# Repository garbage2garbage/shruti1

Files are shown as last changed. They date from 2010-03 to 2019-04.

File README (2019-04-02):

Shruti-1, a digital/analog hybrid MIDI monosynth.

Copyright 2009 Emilie Gillet (emilie.o.gillet@gmail.com)

# The firmware is released under a GPL3.0 license. It includes external code from the following sources:
- Parts of the Arduino library (real time clock and timed delay for software serial).
- Parts of M J Oldfield's makefile for Arduino project.
- A reimplementation of the formant synthesis algorithm used in Peter Knight's Cantarino speech synthesizer.

# The PCB layouts and schematics (in /hardware/shruti/hardware_design) are released under a Creative Commons cc-by-nc-sa 3.0 license.

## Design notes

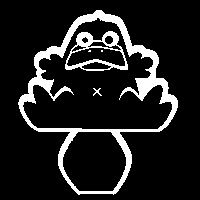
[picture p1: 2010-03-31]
hardware/shruti/hardware_design/pcb/platypus.bmp

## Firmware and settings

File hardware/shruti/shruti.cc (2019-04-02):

// Copyright 2009 Emilie Gillet.
//
// Author: Emilie Gillet (emilie.o.gillet@gmail.com)
//
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
#include "hardware/hal/adc.h"
#include "hardware/hal/audio_output.h"
#include "hardware/hal/devices/output_array.h"
#include "hardware/hal/devices/shift_register.h"
#include "hardware/hal/gpio.h"
#include "hardware/hal/init_atmega.h"
#include "hardware/hal/input_array.h"
#include "hardware/hal/serial.h"
#include "hardware/hal/time.h"
#include "hardware/hal/timer.h"
#include "hardware/midi/midi.h"
#include "hardware/shruti/display.h"
#include "hardware/shruti/editor.h"
#include "hardware/shruti/synthesis_engine.h"
#include "hardware/utils/task.h"

using namespace hardware_hal;
using namespace hardware_midi;
using namespace hardware_shruti;

using hardware_utils::NaiveScheduler;
using hardware_utils::Task;

// Midi input.
Serial<SerialPort0, 31250, BUFFERED, POLLED> midi_io;

// Input event handlers.
typedef InputArray<
    AnalogInput<kPinAnalogInput>,
    kNumEditingPots,
    8> Pots;

typedef InputArray<
    DigitalInput<kPinDigitalInput>,
    kNumGroupSwitches + 2> Switches;

PwmOutput<kPinVcfCutoffOut> vcf_cutoff_out;
PwmOutput<kPinVcfResonanceOut> vcf_resonance_out;
PwmOutput<kPinVcaOut> vca_out;

Pots pots;
Switches switches;

// Shift register for input multiplexer.
ShiftRegister<
    Gpio<kPinInputLatch>,
    Gpio<kPinClk>,
    Gpio<kPinData>, 8, MSB_FIRST> input_mux;

// LED array.
OutputArray<
    Gpio<kPinOutputLatch>, 
    Gpio<kPinClk>,
    Gpio<kPinData>, kNumPages, 4, MSB_FIRST, false> leds;

// Audio output on pin 3.
AudioOutput<PwmOutput<kPinVcoOut>, kAudioBufferSize, kAudioBlockSize> audio_out;

MidiStreamParser<SynthesisEngine> midi_parser;

static const uint16_t kDetailsPageDelay = 900;

// What follows is a list of "tasks" - short functions handling a particular
// aspect of the synth (rendering audio, updating the LCD display, etc). they
// are called in sequence, with some tasks being more frequently called than
// others, by the Scheduler.
void UpdateLedsTask() {
  leds.Clear();
  if (editor.current_page() == PAGE_MOD_MATRIX) {
    uint8_t current_modulation_source_value = engine.modulation_source(0,
        engine.patch().modulation_matrix.modulation[
            editor.subpage()].source);
    leds.set_value(PAGE_MOD_MATRIX, current_modulation_source_value >> 4);
  } else if (editor.current_page() == PAGE_PERFORMANCE) {
    for (uint8_t i = 0; i < kNumModulationDestinations; ++i) {
      leds.set_value(i, engine.voice(0).modulation_destination(i) >> 4);
    }
  } else {
    leds.set_value(editor.current_page(), 15);
  }
  // The led of the arpeggiator page flashes strongly on the 0-th step and
  // weakly on the other steps which are a multiple of 4.
  if (engine.voice_controller().active()) {
    if (!(engine.voice_controller().step() & 3)) {
      leds.set_value(PAGE_LOAD_SAVE, engine.voice_controller().step() ? 1 : 15);
    }
  }
  leds.Output();
}

void UpdateDisplayTask() {
  display.Update();
}

void InputTask() {
  Switches::Event switch_event;
  Pots::Event pot_event;
  static uint8_t idle;
  static uint8_t target_page_type;
TASK_BEGIN_NEAR
  while (1) {
    idle = 0;
    target_page_type = PAGE_TYPE_ANY;
    
    // Read the switches.
    switch_event = switches.Read();
    
    // If a button was pressed, perform the action. Otherwise, if nothing
    // happened for 1.5s, update the idle flag.
    if (switch_event.event == EVENT_NONE) {
      if (switch_event.time > kDetailsPageDelay) {
        idle = 1;
      }
    } else {
      if (switch_event.event == EVENT_RAISED && switch_event.time > 100) {
        uint8_t id = switch_event.id;
        uint8_t hold_time = static_cast<uint16_t>(switch_event.time) >> 8;
        if (id < kNumGroupSwitches) {
          if (hold_time >= 3) {  // 0.768 seconds
            editor.DoShiftFunction(id, hold_time);
          } else {
            editor.ToggleGroup(id);
          }
          target_page_type = PAGE_TYPE_SUMMARY;
        } else {
          editor.HandleIncrement(id == kNumGroupSwitches ? -1 : 1);
          target_page_type = PAGE_TYPE_DETAILS;
        }
      }
    }
    
    // Select which analog/digital inputs we want to read by a write to the
    // multiplexer register.
    input_mux.Write((pots.active_input() << 3) | switches.active_input());    
    pot_event = pots.Read();
    
    // Update the editor if something happened.
    // Revert back to the main page when nothing happened for 1.5s.
    if (pot_event.event == EVENT_NONE) {
      if (idle && pot_event.time > kDetailsPageDelay) {
        target_page_type = PAGE_TYPE_SUMMARY;
      }
    } else {
      editor.HandleInput(pot_event.id, pot_event.value);
      target_page_type = PAGE_TYPE_DETAILS;
    }
    TASK_SWITCH;
    
    if (target_page_type == PAGE_TYPE_SUMMARY) {
      editor.DisplaySummary();
    } else if (target_page_type == PAGE_TYPE_DETAILS) {
      editor.DisplayDetails();
    }
    TASK_SWITCH;
  }
TASK_END
}

uint8_t current_cv;

void CvTask() {
  ++current_cv;
  if (current_cv >= kNumCvInputs) {
    current_cv = 0;
  }
  engine.set_cv(current_cv, Adc::Read(kPinCvInput + current_cv) >> 2);
}

void MidiTask() {
  // Always flush the MIDI buffer before continuing. This makes unlikely the
  // situation where MIDI bytes are dropped... at the cost of a more glitchy
  // audio output in case of MIDI overloading.
  uint8_t status = 0;
  while (midi_io.readable()) {
    uint8_t value = midi_io.ImmediateRead();
    
    // Copy the byte to the MIDI output (thru). We could use Overwrite here
    // since the output rate is the same as the input rate, which ensures that
    // 0.32ms have elapsed between the writes.
    midi_io.Write(value);
    
    // Also, parse the message.
    status = midi_parser.PushByte(value);
    if (engine.patch().kbd_midi_channel >= 17) {
      break;
    }
  }
  // Display a status indicator on the LCD to indicate that a message has
  // been received. This could be done as well in the synthesis engine code
  // or in the MIDI parser, but I'd rather keep the UI code separate.
  switch (status & 0xf0) {
    // Note on/off.
    case 0x90:
      display.set_status('\x01');
      break;
    // Controller.
    case 0xb0:
      display.set_status('\x05');
      break;
    // Bender.
    case 0xe0:
      display.set_status('\x02');
      break;
    // Special messages.
    case 0xf0:
      // Display a status indicator to monitor SysEx patch reception.
      if (status == 0xf0 || status == 0xf7) {
        switch (engine.patch().sysex_reception_state()) {
          case RECEIVING_DATA:
            display.set_status('~');
            break;
          case RECEPTION_OK:
            display.set_status('+');
            engine.TouchPatch();
            break;
          case RECEPTION_ERROR:
            display.set_status('#');
            break;
        }
      }
      break;
  }
}

void AudioRenderingTask() {
  if (audio_out.writable_block()) {
    engine.Control();
    if (engine.voice(0).dead()) {
      for (uint8_t i = kAudioBlockSize; i > 0 ; --i) {
        audio_out.Overwrite(128);
      }
    } else {
      for (uint8_t i = kAudioBlockSize; i > 0 ; --i) {
        engine.Audio();
        audio_out.Overwrite(engine.voice(0).signal());
      }
    }
    vcf_cutoff_out.Write(engine.voice(0).cutoff());
    vcf_resonance_out.Write(engine.voice(0).resonance());
    vca_out.Write(engine.voice(0).vca());
  }
}

uint16_t previous_num_glitches;

// This task displays a '!' in the status area of the LCD displays whenever
// a discontinuity occurred in the audio rendering. Even if the code is
// optimized in such a way that it never occurs, I'd rather keep it here in
// case new features are implemented and need performance monitoring.
// This code uses 42 bytes.
void AudioGlitchMonitoringTask() {
  uint16_t num_glitches = audio_out.num_glitches();
  if (num_glitches != previous_num_glitches) {
    previous_num_glitches = num_glitches;
    display.set_status('!');
  }
}

typedef NaiveScheduler<kSchedulerNumSlots> Scheduler;

Scheduler scheduler;

/* static */
template<>
Task Scheduler::tasks_[] = {
    { &AudioRenderingTask, 16 },
    { &MidiTask, 6 },
    { &UpdateLedsTask, 4 },
    { &UpdateDisplayTask, 2 },
#ifdef HAS_GLITCH_MONITORING
    { &AudioGlitchMonitoringTask, 1 },
#endif  // HAS_GLITCH_MONITORING
    { &InputTask, 2 },
    { &CvTask, 1 },
};

TIMER_2_TICK {
  display.Tick();
  audio_out.EmitSample();
}

void Init() {
  scheduler.Init();
  display.Init();
  editor.Init();
  audio_out.Init();

  // Initialize all the PWM outputs, in 31.25kHz, phase correct mode.
  Timer<1>::set_prescaler(1);
  Timer<1>::set_mode(TIMER_PWM_PHASE_CORRECT);
  Timer<2>::set_prescaler(1);
  Timer<2>::set_mode(TIMER_PWM_PHASE_CORRECT);
  Timer<2>::Start();
  vcf_cutoff_out.Init();
  vcf_resonance_out.Init();
  vca_out.Init();
  
  display.SetBrightness(29);
  display.SetCustomCharMap(character_table[0], 8);
  editor.DisplaySplashScreen(STR_RES_MUTABLE____V0_59);
  
  midi_io.Init();
  pots.Init();
  switches.Init();
  DigitalInput<kPinDigitalInput>::EnablePullUpResistor();
  input_mux.Init();
  leds.Init();  
  
  engine.Init();
}

int main(void) {
  InitAtmega(false);  // Do not initialize timers 1 & 2.
  Init();
  scheduler.Run();
}

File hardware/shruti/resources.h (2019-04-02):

// Copyright 2009 Emilie Gillet.
//
// Author: Emilie Gillet (emilie.o.gillet@gmail.com)
//
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
// -----------------------------------------------------------------------------
//
// Resources definitions.
//
// Automatically generated with:
// make resources


#ifndef HARDWARE_SHRUTI_RESOURCES_H_
#define HARDWARE_SHRUTI_RESOURCES_H_


#include "hardware/base/base.h"

#include <avr/pgmspace.h>


#include "hardware/resources/resources_manager.h"
namespace hardware_shruti {

typedef uint8_t ResourceId;

extern const prog_char* string_table[];

extern const prog_uint16_t* lookup_table_table[];

extern const prog_uint8_t* waveform_table[];

extern const prog_uint8_t* character_table[];

extern const prog_uint16_t lut_res_lfo_increments[] PROGMEM;
extern const prog_uint16_t lut_res_env_portamento_increments[] PROGMEM;
extern const prog_uint16_t lut_res_oscillator_increments[] PROGMEM;
extern const prog_uint16_t lut_res_fm_frequency_ratios[] PROGMEM;
extern const prog_uint16_t lut_res_scale_just[] PROGMEM;
extern const prog_uint16_t lut_res_scale_pythagorean[] PROGMEM;
extern const prog_uint16_t lut_res_scale_1_4_eb[] PROGMEM;
extern const prog_uint16_t lut_res_scale_1_4_e[] PROGMEM;
extern const prog_uint16_t lut_res_scale_1_4_ea[] PROGMEM;
extern const prog_uint16_t lut_res_scale_bhairav[] PROGMEM;
extern const prog_uint16_t lut_res_scale_gunakri[] PROGMEM;
extern const prog_uint16_t lut_res_scale_marwa[] PROGMEM;
extern const prog_uint16_t lut_res_scale_shree[] PROGMEM;
extern const prog_uint16_t lut_res_scale_purvi[] PROGMEM;
extern const prog_uint16_t lut_res_scale_bilawal[] PROGMEM;
extern const prog_uint16_t lut_res_scale_yaman[] PROGMEM;
extern const prog_uint16_t lut_res_scale_kafi[] PROGMEM;
extern const prog_uint16_t lut_res_scale_bhimpalasree[] PROGMEM;
extern const prog_uint16_t lut_res_scale_darbari[] PROGMEM;
extern const prog_uint16_t lut_res_scale_rageshree[] PROGMEM;
extern const prog_uint16_t lut_res_scale_khamaj[] PROGMEM;
extern const prog_uint16_t lut_res_scale_mimal[] PROGMEM;
extern const prog_uint16_t lut_res_scale_parameshwari[] PROGMEM;
extern const prog_uint16_t lut_res_scale_rangeshwari[] PROGMEM;
extern const prog_uint16_t lut_res_scale_gangeshwari[] PROGMEM;
extern const prog_uint16_t lut_res_scale_kameshwari[] PROGMEM;
extern const prog_uint16_t lut_res_scale_palas_kafi[] PROGMEM;
extern const prog_uint16_t lut_res_scale_natbhairav[] PROGMEM;
extern const prog_uint16_t lut_res_scale_m_kauns[] PROGMEM;
extern const prog_uint16_t lut_res_scale_bairagi[] PROGMEM;
extern const prog_uint16_t lut_res_scale_b_todi[] PROGMEM;
extern const prog_uint16_t lut_res_scale_chandradeep[] PROGMEM;
extern const prog_uint16_t lut_res_scale_kaushik_todi[] PROGMEM;
extern const prog_uint16_t lut_res_scale_jogeshwari[] PROGMEM;
extern const prog_uint16_t lut_res_arpeggiator_patterns[] PROGMEM;
extern const prog_uint16_t lut_res_turbo_tempi[] PROGMEM;
extern const prog_uint16_t lut_res_groove_swing[] PROGMEM;
extern const prog_uint16_t lut_res_groove_shuffle[] PROGMEM;
extern const prog_uint16_t lut_res_groove_push[] PROGMEM;
extern const prog_uint16_t lut_res_groove_lag[] PROGMEM;
extern const prog_uint16_t lut_res_groove_human[] PROGMEM;
extern const prog_uint8_t wav_res_formant_sine[] PROGMEM;
extern const prog_uint8_t wav_res_formant_square[] PROGMEM;
extern const prog_uint8_t wav_res_bandlimited_square_0[] PROGMEM;
extern const prog_uint8_t wav_res_bandlimited_square_1[] PROGMEM;
extern const prog_uint8_t wav_res_bandlimited_square_2[] PROGMEM;
extern const prog_uint8_t wav_res_bandlimited_square_3[] PROGMEM;
extern const prog_uint8_t wav_res_bandlimited_square_4[] PROGMEM;
extern const prog_uint8_t wav_res_bandlimited_square_5[] PROGMEM;
extern const prog_uint8_t wav_res_bandlimited_square_6[] PROGMEM;
extern const prog_uint8_t wav_res_bandlimited_saw_0[] PROGMEM;
extern const prog_uint8_t wav_res_bandlimited_saw_1[] PROGMEM;
extern const prog_uint8_t wav_res_bandlimited_saw_2[] PROGMEM;
extern const prog_uint8_t wav_res_bandlimited_saw_3[] PROGMEM;
extern const prog_uint8_t wav_res_bandlimited_saw_4[] PROGMEM;
extern const prog_uint8_t wav_res_bandlimited_saw_5[] PROGMEM;
extern const prog_uint8_t wav_res_bandlimited_triangle_0[] PROGMEM;
extern const prog_uint8_t wav_res_bandlimited_triangle_1[] PROGMEM;
extern const prog_uint8_t wav_res_bandlimited_triangle_2[] PROGMEM;
extern const prog_uint8_t wav_res_bandlimited_triangle_3[] PROGMEM;
extern const prog_uint8_t wav_res_bandlimited_triangle_4[] PROGMEM;
extern const prog_uint8_t wav_res_bandlimited_triangle_5[] PROGMEM;
extern const prog_uint8_t wav_res_wavetable[] PROGMEM;
extern const prog_uint8_t wav_res_vowel_data[] PROGMEM;
extern const prog_uint8_t chr_res_special_characters[] PROGMEM;
#define STR_RES_PRM 0  // prm
#define STR_RES_RNG 1  // rng
#define STR_RES_OP 2  // op
#define STR_RES_TUN 3  // tun
#define STR_RES_PRT 4  // prt
#define STR_RES_PORTA 5  // porta
#define STR_RES_PARAMETER 6  // parameter
#define STR_RES_RANGE 7  // range
#define STR_RES_OPERATOR 8  // operator
#define STR_RES_DETUNE 9  // detune
#define STR_RES_OSC_BAL 10  // osc bal
#define STR_RES_SUB_OSC_ 11  // sub osc.
#define STR_RES_PATTERN 12  // pattern
#define STR_RES_GROOVE 13  // groove
#define STR_RES_OSCILLATOR_1 14  // oscillator 1
#define STR_RES_OSCILLATOR_2 15  // oscillator 2
#define STR_RES_ARPEGGIO 16  // arpeggio
#define STR_RES_PERFORMANCE 17  // performance
#define STR_RES_NONE 18  // none
#define STR_RES_BLIT 19  // blit
#define STR_RES_SAW 20  // saw
#define STR_RES_SQUARE 21  // square
#define STR_RES_TRIANG 22  // triang
#define STR_RES_CZ 23  // cz
#define STR_RES_FM 24  // fm
#define STR_RES_8BITS 25  // 8bits
#define STR_RES_PWM 26  // pwm
#define STR_RES_NOISE 27  // noise
#define STR_RES_VOWEL 28  // vowel
#define STR_RES_WAVTBL 29  // wavtbl
#define STR_RES_SWEEP 30  // sweep
#define STR_RES_ZSYNC 31  // zsync
#define STR_RES_PAD 32  // pad
#define STR_RES_1S2 33  // 1+2
#define STR_RES_1_2 34  // 1>2
#define STR_RES_1P2 35  // 1*2
#define STR_RES_1X2 36  // 1^2
#define STR_RES_CUT 37  // cut
#define STR_RES_VCA 38  // vca
#define STR_RES_PW1 39  // pw1
#define STR_RES_PW2 40  // pw2
#define STR_RES_51 41  // 1
#define STR_RES_52 42  // 2
#define STR_RES_5 43  // 
#define STR_RES_MIX 44  // mix
#define STR_RES_NOI 45  // noi
#define STR_RES_SUB 46  // sub
#define STR_RES_RES 47  // res
#define STR_RES_CUTOFF 48  // cutoff
#define STR_RES__VCA 49  //  vca
#define STR_RES_PWM1 50  // pwm1
#define STR_RES_PWM2 51  // pwm2
#define STR_RES_OSC1 52  // osc1
#define STR_RES_OSC2 53  // osc2
#define STR_RES_OSC1S2 54  // osc1+2
#define STR_RES__MIX 55  //  mix
#define STR_RES__NOISE 56  //  noise
#define STR_RES_SUBOSC 57  // subosc
#define STR_RES_RESO 58  // reso
#define STR_RES_ATK 59  // atk
#define STR_RES_WV1 60  // wv1
#define STR_RES_RT1 61  // rt1
#define STR_RES_WV2 62  // wv2
#define STR_RES_RT2 63  // rt2
#define STR_RES_SRC 64  // src
#define STR_RES_DST 65  // dst
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

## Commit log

2009-08-22 - Refactoring of LFOs as classes. - Refactoring of Display driver as static'ified class. - More informative header in the modulation matrix page.
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2009-08-22 Bug fixes and small improvements in speed and code size: - Added a 33th waveform (a copy of the 1st) as a sentinel. - Reduced the size of the blit/square code. - Renamed wavetable functions (256/64 i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
    [editor.h, oscillator.h, resources.cc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]
2009-08-23 - added crossfading between each zone's waveform, for the basic saw and square waveforms. - switched to 16kHz output. - changed the wirings to prepare for dual DAC output. - added functions for nibbl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
    [oscillator.h, resources.cc, shruti.cc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]
2009-08-23 - Moved "drivers" for external circuits in "devices" subdirectory. - Changed my name to my google id to my github id. - SPI interface + driver for 492x DACs (not used yet in the synth code for perfor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
2009-08-24 - Fixed lame bug in midi stream parser. - Fixed lame bugs in resources compiler. - MIDI! - Many bugs fixed in envelope code. - (Temporary) software VCA. - Pitch bend in -2/2 semitones range.
2009-08-25 First pass for hybrid (31.25kHz for saw/square, 15.625kHz for the rest) oscillators. !! Still glitchy for 3 square waves. !! Voice oscillator seems to be broken.
    [oscillator.h, resources.cc, resources.h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]
2009-08-26 A couple of steps towards good performances at 32kHz... - Minor cosmetic/stylistic changes. - Added status indicator in display (MIDI notes, glitches). - Sub-oscillator is now specialized, and runs a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
    [adc.cc, adc.h, init_arduino.cc]
2009-08-27 - Removed unnecessary oscillator reset code. - Removed large block of inlined asm (InterpolateTwoTables). It was not much faster and caused weird register conflicts. - Simplified the oscillators code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
    [oscillator.h, resources.cc, resources.h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]
2009-08-27 - Control signals for the curtis filter are now written to the PWM outputs. - Fixed a bug with the splashscreen+status.
    [oscillator.h, resources.cc, resources.h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]
2009-08-27 Code optimizations: - No check on disabled oscillators. This makes the code run much slower in the typical case, but makes it run faster on the worst case (and we're interested in avoiding bugs in th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
    [oscillator.h, synthesis_engine.cc]
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2009-09-03 Added EAGLE schematics and board designs.
    [Shruti-FrontPanel-v01.brd, Shruti-FrontPanel-v01.sch, Shruti-Main-v01.brd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]
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2009-09-15 - fixed minor style issues in a couple of classes. - simplified some pure stateless tasks. - implemented a very naive scheduler to adjust priorities / scan rates / refresh rates for each task. No mor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
    [Shruti-Main-v01.brd, Shruti-Main-v01.sch]
2009-09-15 - fixed the way signed parameters are defined. - remove ramp up / ramp down distinction (ramp down can be obtained with a ramp up and a negative modulation amount). - extended the size of the modulat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
    [editor.h, oscillator.h, patch.h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]
2009-09-16 - in order to save space, removed short parameter names when they were the first letters of the long name. - moved patch load/save code to the Patch class. - added easter egg. - revised oscillator pr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
    [editor.h, oscillator.h, patch.h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]
2009-09-16 - Added delay function. - Added delays before/after sending the baud rate change command to the LCD. This almost solves the "boot up in 9600bps mode" problem. - Added noinline attributes here and the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
    [init_arduino.cc]
2009-09-16 - FM and phase distortion now run at sr! - FM has been replaced by phase distortion - the results are sonically very similar anyway.
    [oscillator.h, patch.h, shruti.cc]
2009-09-17 - Renamed the Signal class Op, since all the optimized routines here are no longer specific to signal/samples manipulation. - Removed unused custom characters. Instead, added a lame "shruti-1" devana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
    [oscillator.h, resources.cc, resources.h]
2009-09-17 - Shifted the phase of all the waveforms by 90° to fix a bug with cz sweep. - Adopted a new strategy for dealing with the computational cost of the "voice" oscillator: when this algorithm is used, th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
    [oscillator.h, resources.cc, synthesis_engine.cc]
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2009-09-21 - Added a "silent" "oscillator", called "none", which is useful when processing external signals. - The envelope/LFO modulation settings directly accessible on the filter page are no longer polarized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
    [Shruti-Main-v01.brd, Shruti-Main-v01.sch]
2009-09-27 First pass on the code for style/minor issues.
    [oscillator.h, patch.h, resources.cc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]
2009-09-27 Another pass of style corrections
    [shruti.cc]
2009-09-28 Another pass of optimizations. The torture-test patch now runs without glitches!
    [oscillator.h, shruti.cc, synthesis_engine.cc]
2009-10-12 Revised schematics and PCB designs.
    [Shruti-FrontPanel-v01.brd, Shruti-FrontPanel-v01.sch, Shruti-Main-v01.brd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]
2009-10-24 main PCB update
    [Shruti-Main-v01.brd, Shruti-Main-v01.sch]
2009-11-07 PCB review
    [Shruti-FrontPanel-v01.brd, Shruti-FrontPanel-v01.sch, Shruti-Main-v01.brd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]
2009-11-08 - PCB: removed caps on 74hc595s' latches. This was stupid, indeed. - PCB: reworked the layout of the main board so that it can act as a "shield" for the arduino (less cables!!!). - PCB: added funky s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
    [Shruti-FrontPanel-v01.brd, Shruti-FrontPanel-v01.sch, Shruti-Main-v01.brd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]
2009-11-09 Added GPL notice to all source files, cc-by-nc-sa to all PCB design files
    [Shruti-FrontPanel-v01.brd, Shruti-Main-v01.brd]
2009-11-14 Minor corrections to comments/README
    [synthesis_engine.cc]
2009-11-17 Added new PCB layouts: front panel shrinked to 50% of its original size, main board with ATMega328P
    [Shruti-FrontPanel-v01.brd, Shruti-FrontPanel-v02.brd, Shruti-FrontPanel-v02.sch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]
2009-11-20 New power supply
    [Shruti-FrontPanel-v02.brd, Shruti-Main-v02.brd, Shruti-Main-v02.sch]
2009-11-20 Minor PCB tweaks
    [Shruti-FrontPanel-v02.brd, Shruti-Main-v02.brd]
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2009-11-21 Fixed synchronizations problems for tempo-synced LFOs and arpeggiator. This has a slightly annoying side-effect: when pressing a key, there might be a slight delay (< 1 step) before the arpeggiator k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
    [oscillator.h, synthesis_engine.cc]
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2009-11-23 - Revised MIDI in (removed pull-up). - Revised expansion connector (added RST which is required for flashing the firmware, added +5V). - Power supply with MAX1044.
    [Shruti-Main-v01.brd, Shruti-Main-v01.sch, Shruti-Main-v02.brd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]
2009-11-25 PCB improvements
    [Shruti-FrontPanel-v02.brd, Shruti-FrontPanel-v02.sch, Shruti-Main-v02.brd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]
2009-11-26 - Deprecated versions 0.1 of the PCBs. - PCB tweaks. - Replaced references to arduino to "atmega", since we do not rely anymore on arduino stuff (except for the bootloader and the toolchain installat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
    [Shruti-FrontPanel-v01.brd, Shruti-FrontPanel-v01.sch, Shruti-FrontPanel-v02.brd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]
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2009-12-03 Display initialization code was called twice. might be intentional (serial LCD initialization problems)
    [shruti.cc, synthesis_engine.cc]
2009-12-05 - PCB: changed the spacing between the connectors to have the top hole in a more convenient location. - Added exclusive-or modulation, for those who have kittens to kill. - Removed some initializatio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
    [Shruti-Main-v02.brd, Shruti-Main-v02.sch]
2009-12-08 - reduced code size for the Delay function - PWM refactoring. Now using xfading (no more annoying transitions when switching from one zone to another). - Looked at the waveforms in audacity, tweak Ju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
    [Shruti-Main-v02.brd, Shruti-Main-v02.sch]
2009-12-12 Revised front panel PCB with on-board omron switches and alps pots
    [Shruti-FrontPanel-v02.brd, Shruti-FrontPanel-v02.sch]
2009-12-13 Re-routed PCBs
    [Shruti-FrontPanel-v02.brd, Shruti-FrontPanel-v02.sch, Shruti-Main-v02.brd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]
2009-12-14 Sunday night PCB tweaks
    [Shruti-FrontPanel-v03.brd, Shruti-FrontPanel-v03.sch, Shruti-Main-v03.brd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]
2009-12-14 Minor code tweaks
    [Shruti-FrontPanel-v03.brd, Shruti-FrontPanel-v03.sch, Shruti-Main-v03.brd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]
2009-12-14 Changed the stage at which the 'use wavetable for square when pw=50%' hack is applied. Before, it was in the rendering function. It is now done when setting up which rendering routine to call. This s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
    [Shruti-FrontPanel-v03.brd, Shruti-Main-v03.brd]
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2009-12-18 Removed "__TEST__". Will eventually switch to simavr.
    [Shruti-FrontPanel-v03.brd, Shruti-FrontPanel-v03.sch, Shruti-Main-v03.brd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]
2009-12-22 - Tweaked the init patch - Increased the range of the LFOs
    [Shruti-FrontPanel-v03.brd, Shruti-FrontPanel-v03.sch, Shruti-Main-v03.brd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]
2009-12-30 - Now using avr-nm to get list of top symbols (d'oh) - Fixed a 90° trace on the PCB
    [Shruti-Main-v03.brd]
2009-12-30 Added two oscillator algorithms: - dirty pwm (fat, but with aliasing). - colored noise.
    [oscillator.h, patch.h, resources.cc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]
2009-12-30 - Changed the order of the oscillators algorithms and updated the patch library accordingly - Fixed a bug occuring when loading a patch while a patch using wave sequencing was playing
    [oscillator.h, patch.h, resources.cc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]
2009-12-30 Better fix for the wave sequencing bug
    [oscillator.h]
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2009-12-30 Added new arpeggiator patterns and reworked the display of the pattern "name".
    [patch.h, resources.cc, resources.h]
2009-12-31 Updated directory structure to build two versions of the firmware (mono synth and string synth).
    [Shruti-FrontPanel-v03.brd, Shruti-FrontPanel-v03.sch, Shruti-Main-v03.brd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]
2010-01-03 PCB fixes: fixed audio output, removed variable gain circuit, moved pin header down
    [Shruti-Main-v03.brd, Shruti-Main-v03.sch]
2010-01-05 Forked Shruti-4
    [Shruti-Main-v03.brd, Shruti-Main-v03.sch]
2010-01-06 Removed design discussion from README + Added more space between pots on facade PCB
    [Shruti-FrontPanel-v03.brd, Shruti-FrontPanel-v03.sch, Shruti-Main-v03.brd]
2010-01-07 Removed assignable pots from front panel
    [Shruti-FrontPanel-v03.brd, Shruti-FrontPanel-v03.sch]
2010-01-07 Fixed problem with MIDI output
    [Shruti-Main-v03.brd, Shruti-Main-v03.sch]
2010-01-08 Arpeggiator code simplification + assignable bug fix
    [shruti.cc, shruti.h]
2010-01-08 Thread-unsafe Itoa to avoid allocating too much crap on the stack
    [oscillator.h, synthesis_engine.cc]
2010-01-09 Redesigned from scratch the main PCB
    [Shruti-FrontPanel-v03.brd, Shruti-FrontPanel-v04.brd, Shruti-FrontPanel-v04.sch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]
2010-01-09 Cleaned up makefile
    [Shruti-FrontPanel-v04.brd, Shruti-Main-v04.brd]
2010-01-09 New layout for the front panel board
    [Shruti-FrontPanel-v04.brd, Shruti-Main-v04.brd]
2010-01-11 Increased trace width for GND/+5/-5
    [Shruti-Main-v04.brd]
2010-01-12 More PCB tweaks
    [Shruti-FrontPanel-v04.brd, Shruti-FrontPanel-v04.sch, Shruti-Main-v04.brd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]
2010-01-13 PCB tweaks
    [Shruti-FrontPanel-v04.brd, Shruti-Main-v04.brd, Shruti-Main-v04.sch]
2010-01-17 Hunting caps in the audio path
    [Shruti-FrontPanel-v04.brd, Shruti-Main-v04.brd, Shruti-Main-v04.sch]
2010-01-17 Fixed bug when going to performance page from performance page; added abort to parameter assignment; simplified page cycling code
    [editor.h]
2010-01-19 Fixed names in editor code
    [Shruti-Main-v04.brd]
2010-01-24 A long press on the load/save page displays a message on screen and soft-resets the Shruti-1. This will be detected by the bootloader to jump into SysEx firmware flashing
    [editor.h, hal.h, resources.cc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]
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2010-01-26 Bootloader: smaller delay ; orange LED flashes on errors
    [bootloader.cc]
2010-01-31 - Found a problem in the bootloader. Under mysterious circumstances, the jump to the main firmware code (0x0000) would not be executed and the Shruti-1 would crash in bootloader limbo. I could reprod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
    [bootloader.cc, shruti.cc, synthesis_engine.cc]
2010-02-01 No typedef-like instantiation for oscillators
    [oscillator.h, synthesis_engine.cc]
2010-02-06 PCB revisions
    [Shruti-FrontPanel-v04.brd, Shruti-FrontPanel-v04.sch, Shruti-Main-v04.brd]
2010-02-06 Did not pass DRC because of clearance problem. Fixed
    [Shruti-Main-v04.brd]
2010-02-09 Final PCB design. Phew
    [Shruti-FrontPanel-v04.brd, Shruti-FrontPanel-v05.brd, Shruti-FrontPanel-v05.sch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]
2010-02-12 Removed milling layers from PCBs
    [Shruti-FrontPanel-v05.brd, Shruti-Main-v05.brd, Shruti-Main-v05.sch]
2010-02-14 Schematics tweaks + started on an alternative design of the front panel that uses a standard LCD module directly soldered on the front panel PCB
    [Shruthi-ControlPanel-v01.brd, Shruthi-ControlPanel-v01.sch, Shruti-FrontPanel-v05.brd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]
2010-02-27 New patches: tampupad, FM Glass, Caracroq, Goarp
    [Shruthi-ControlPanel-v01.brd, Shruthi-ControlPanel-v01.sch]
2010-02-27 Patch fixes, better support for legato/slides
    [patch.h, synthesis_engine.cc]
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2010-03-12 Fixed bug when overlapping notes are played. Had to disable glitch monitoring to make it fit in the firmware.
    [shruti.cc]
2010-03-20 Reworked wavetable oscillator ; Fixed bug with LCD showing garbage when data was sent during startup ; added option to toggle the splash screen
    [Shruti-Main-v05.brd]
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2010-03-28 Fixed bug in load/save page labels
    [resources.cc, resources.h, shruti.cc]
2010-03-31 Added alternate PCB design
    [Shruti-FrontPanel-v05.brd, Shruti-Main-v05.brd]
2010-04-05 Cleaner frames on schematics
    [Shruti-FrontPanel-v05.brd, Shruti-FrontPanel-v05.sch, Shruti-Main-v05.sch]
2010-04-07 Changed text layout for Platypus version
    [Shruti-FrontPanel-v05.brd, Shruti-Main-v05.brd]
2010-04-08 Fixed implementation of ragas. Added data for some more inspiring hindustani ragas instead of a big matrix of carnatic ragas
    [resources.cc, resources.h, shruti.cc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]
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2010-04-20 Oscillator fixes, new ZSync oscillator, new sequence/arpeggio modes
    [oscillator.h, patch.h, resources.cc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]
2010-04-22 New pad waveform + MIDI fix
    [oscillator.h, patch.h, resources.cc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]
2010-05-05 Firmware v0.56: panic, random patch, init, pop fix, new groove templates instead of swing, and higher priority MIDI handling
    [editor.h, patch.h, resources.cc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]
2010-05-14 Hardware glitch fixes for the main board. untested
    [Shruti-Main-v06 untested.brd, Shruti-Main-v06 untested.sch]
2010-05-14 Fixed clock update bug
    [Shruti-Main-v06 untested.brd]
2010-05-15 PCB tweak
    [Shruti-Main-v06 untested.brd, Shruti-Main-v06 untested.sch]
2010-06-16 - Added multiples of the MIDI clock as tempo settings for the arpeggiator/step sequencer. - Some simplification of the UI code handling the display of the extra tempi. - Some simplifications of the c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
    [oscillator.h, resources.cc, resources.h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]
2010-07-25 Removed easter egg, added support for hold pedal, fixed wavetable bug
    [oscillator.h, resources.cc, resources.h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]
2011-04-30 board tweaks
    [Shruti-FrontPanel-v05.brd, Shruti-Main-v05.brd, Shruti-Main-v05.sch]
2019-04-02 Updated name
    [Shruti-FrontPanel-v05.sch, Shruti-Main-v05.brd, Shruti-Main-v05.sch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]

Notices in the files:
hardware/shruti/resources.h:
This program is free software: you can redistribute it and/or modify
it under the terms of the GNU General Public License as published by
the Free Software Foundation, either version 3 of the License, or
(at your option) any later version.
